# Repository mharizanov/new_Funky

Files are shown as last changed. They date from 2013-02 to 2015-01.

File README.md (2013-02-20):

Funky v2
=========

The Funky v2 is a miniature Arduino Leonardo clone with RFM12B module, intended for low power, battery operated remote node. Due to the miniature size, only few carefully selected pins are available as a side header, none the less that is more than sufficient to interface several sensors at a time.

Having gained experience with my Funky v1 project, I decided to create a new version. The project is a success, yet the areas I wanted to optimize are

The Attiny84 MCU that was used in the Funky v1 has limited RAM and sketch memory
The Attiny84 requires an ISP programmer for sketch uploading
The Attiny84 required a modified Arduino core
Many of the available Arduino libraries are not compatible with Attiny84
So the Funky v2 was created, see my posts here , here and here

Board size is mere 22×22.8mm (0.87″x0.89″) in size (same as Funky v1)
The MCU used in an Atmega32U4, the same MCU that Arduino Leonardo uses. This makes the Funky v2 a minuature Arduino Leonardo compatible board with RFM12b module
The Funky v2 has the Caterina bootloader, so programming is done with Arduino IDE via micro USB
Uses external 8Mhz crystal (can switch to internal RC clock in software as described here)
Operates on 3.3V

Read more http://harizanov.com/wiki/wiki-home/funky-sensor-v2/

Licensed under a Creative Commons Attribution-NonCommercial-ShareAlike 3.0 Unported License.

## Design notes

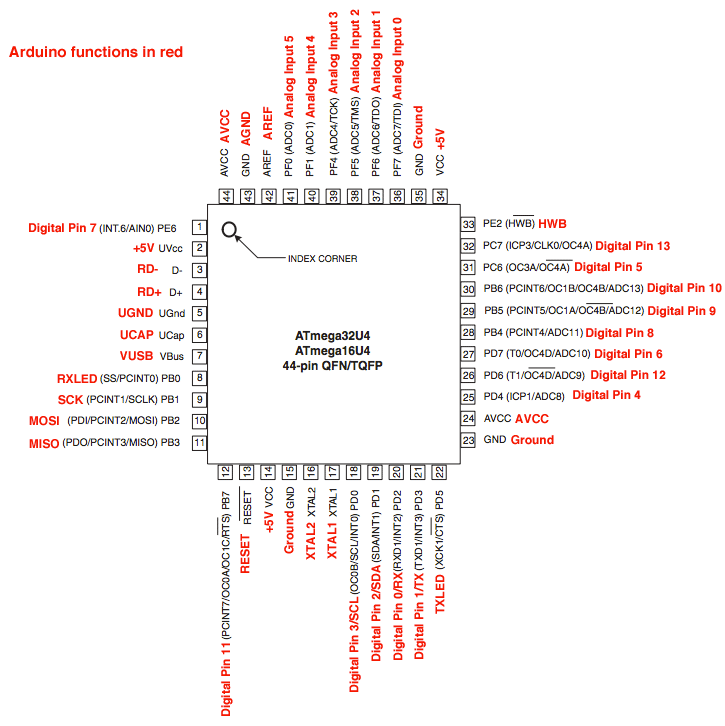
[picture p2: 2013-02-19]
32U4PinMapping.png

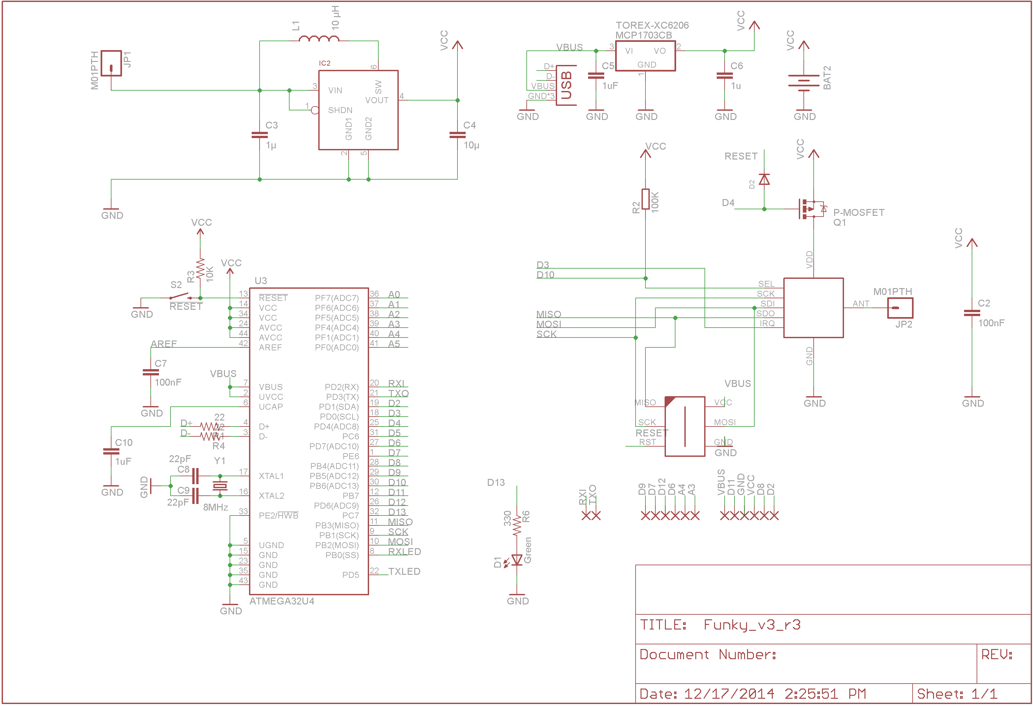
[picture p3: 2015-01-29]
board/v3/funky_v3_r3.sch.png

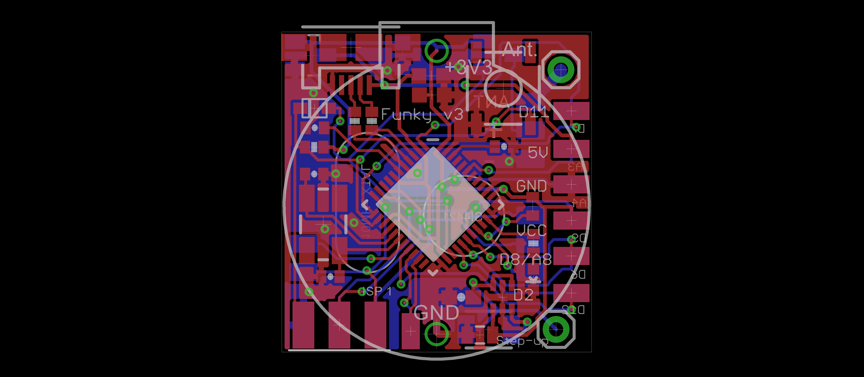
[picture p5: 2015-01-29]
board/v3/funky_v3_r3.brd.png

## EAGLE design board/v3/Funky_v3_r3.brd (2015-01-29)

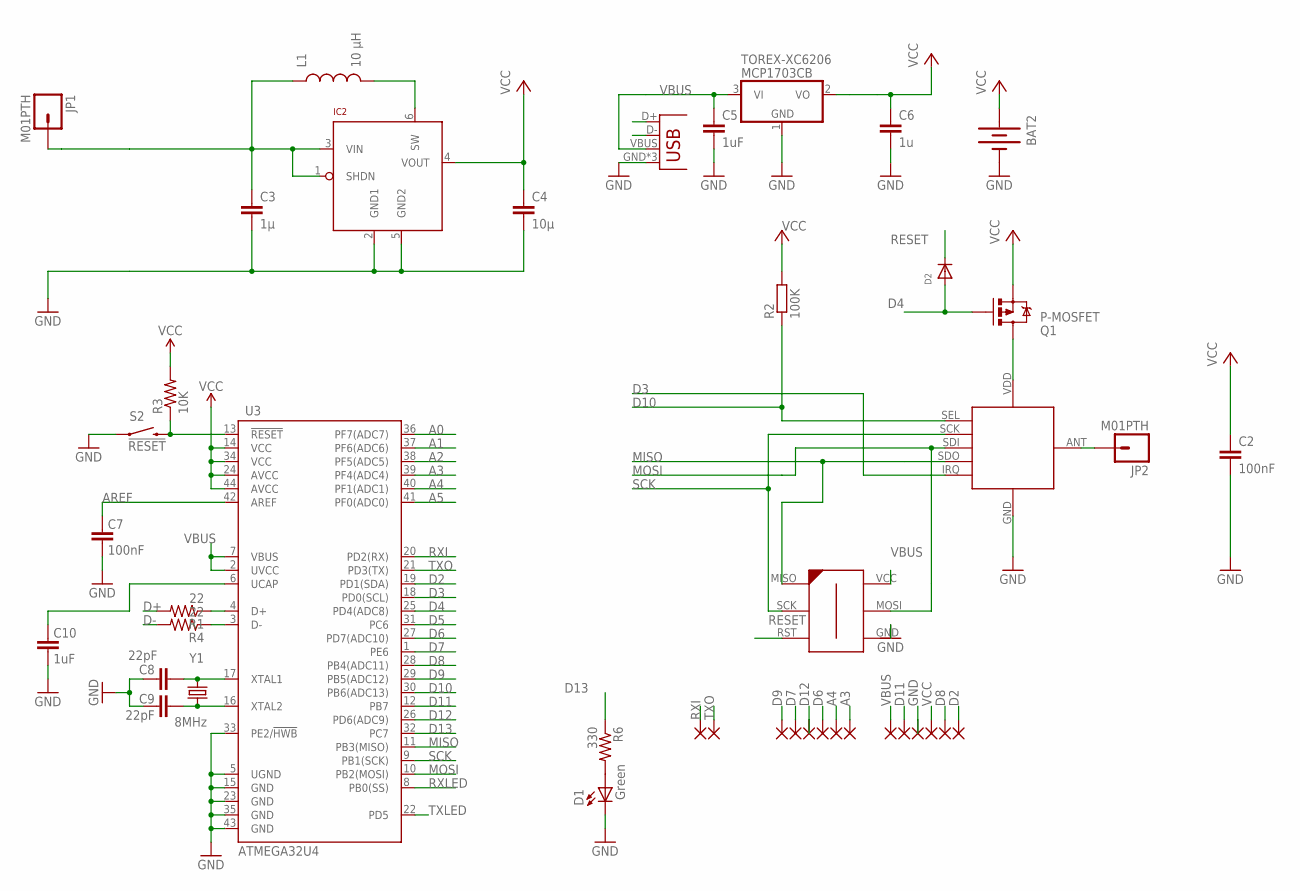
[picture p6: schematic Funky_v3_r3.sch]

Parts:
BAT2: BATTERY20PTH; BATTCOM_20MM_PTH
C2: 100nF; C0603K
C3: 1µ; 0603-CAP
C4: 10µ; 0805
C5: 1uF; C0603K
C6: 1u; C0603K
C7: 100nF; 0402-CAP
C8, C9: 22pF; 0402-CAP
C10: 1uF; 0402-CAP
D1: Green; LED-0603
D2: DIODESOD-323F; SOD-323F
IC2: LTC3525; SC70
JP1, JP2: M01PTH; 1X01
JP3: USB-MICROB
L1: 10 µH; 1210
PAD1, PAD2, PAD3, PAD4, PAD5, PAD6, PAD7, PAD8, PAD9, PAD10, PAD11, PAD12, PAD13, PAD14: SMD2; SMD1,27-2,54
Q1: P-MOSFET; SOT23
R1, R4: 22; 0402-RES
R2: 100K; R0402
R3: 10K; 0402-RES
R6: 330; 0402-RES
RFM12B1: RFM12B_MINPADS; RFM12B-MINPADS
S2: !RESET; TACTILE_SWITCH_SMD
TOREX-XC6206: MCP1703CB; SOT23
U3: ATMEGA32U4; QFN-44-NOPAD
U$2: AVR-ISP-6-EDGE; 6PAD_ISP
Y1: 8MHz; CRYSTAL-SMD-5X3

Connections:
A0: U3.36 (PF7(ADC7))
A1: U3.37 (PF6(ADC6))
A2: U3.38 (PF5(ADC5))
A3: PAD6.1, U3.39 (PF4(ADC4))
A4: PAD5.1, U3.40 (PF1(ADC1))
A5: U3.41 (PF0(ADC0))
AREF: C7.2, U3.42 (AREF)
D2: PAD12.1, U3.19 (PD1(SDA))
D3: RFM12B1.IRQ, U3.18 (PD0(SCL))
D4: D2.A, Q1.1 (G), U3.25 (PD4(ADC8))
D5: U3.31 (PC6)
D6: PAD4.1, U3.27 (PD7(ADC10))
D7: PAD2.1, U3.1 (PE6)
D8: PAD11.1, U3.28 (PB4(ADC11))
D9: PAD1.1, U3.29 (PB5(ADC12))
D10: R2.1, RFM12B1.SEL, U3.30 (PB6(ADC13))
D11: PAD7.1, U3.12 (PB7)
D12: PAD3.1, U3.26 (PD6(ADC9))
D13: R6.1, U3.32 (PC7)
D+: JP3.D+, R1.2
D-: JP3.D-, R4.2
GND: BAT2.2 (-), C2.2, C3.2, C4.2, C5.2, C6.2, C7.1, C8.2, C9.2, C10.1, D1.C, IC2.2 (GND1), IC2.5 (GND2), JP3.GND, JP3.MT1 (GND), JP3.MT2 (GND), PAD9.1, RFM12B1.GND, S2.1, TOREX-XC6206.1 (GND), U3.5 (UGND), U3.15 (GND), U3.23 (GND), U3.33 (PE2/!HWB), U3.35 (GND), U3.43 (GND), U$2.GND
MISO: RFM12B1.SDO (SDO/MISO), U3.11 (PB3(MISO)), U$2.MISO
MOSI: RFM12B1.SDI (SDI/MOSI), U3.10 (PB2(MOSI)), U$2.MOSI
unnamed: C9.1, U3.16 (XTAL2), Y1.1
unnamed: R1.1, U3.4 (D+)
unnamed: JP2.1, RFM12B1.ANT
unnamed: C8.1, U3.17 (XTAL1), Y1.3 (2)
unnamed: C10.2, U3.6 (UCAP)
unnamed: D1.A, R6.2
unnamed: R4.1, U3.3 (D-)
unnamed: Q1.3 (D), RFM12B1.VDD
unnamed: IC2.6 (SW), L1.2
RESET: D2.C, R3.1, S2.3 (2), U3.13 (!RESET), U$2.RST
RXI: PAD14.1, U3.20 (PD2(RX))
RXLED: U3.8 (PB0(SS))
SCK: RFM12B1.SCK, U3.9 (PB1(SCK)), U$2.SCK
TXLED: U3.22 (PD5)
TXO: PAD13.1, U3.21 (PD3(TX))
VBUS: C5.1, JP3.VBUS, PAD8.1, TOREX-XC6206.3 (VI), U3.2 (UVCC), U3.7 (VBUS), U$2.VCC
VCC: BAT2.1 (+), C2.1, C4.1, C6.1, IC2.4 (VOUT), PAD10.1, Q1.2 (S), R2.2, R3.2, TOREX-XC6206.2 (VO), U3.14 (VCC), U3.24 (AVCC), U3.34 (VCC), U3.44 (AVCC)
VIN: C3.1, IC2.1 (SHDN), IC2.3 (VIN), JP1.1, L1.1

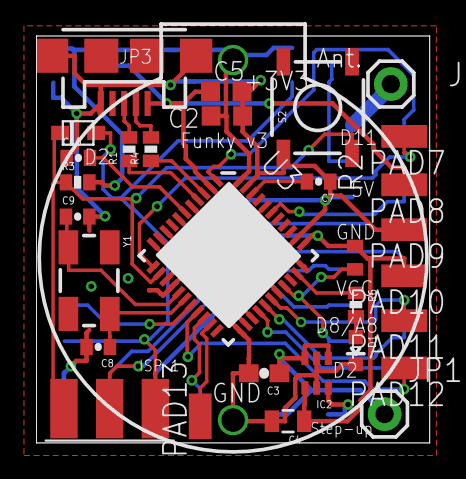
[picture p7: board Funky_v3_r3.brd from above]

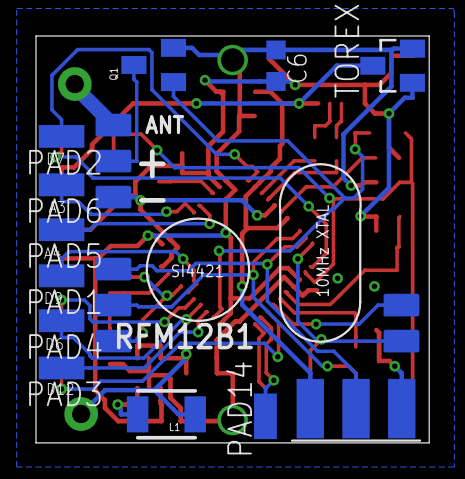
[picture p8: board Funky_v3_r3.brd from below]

Board: 2 copper layers, 21.8 x 22.6 mm, 43 parts (12 on the bottom side), 35 nets.

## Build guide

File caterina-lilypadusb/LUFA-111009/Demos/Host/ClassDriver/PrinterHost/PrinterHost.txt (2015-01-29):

/** \file
 *
 *  This file contains special DoxyGen information for the generation of the main page and other special
 *  documentation pages. It is not a project source file.
 */

/** \mainpage Printer Host Demo
 *
 *  \section Sec_Compat Demo Compatibility:
 *
 *  The following list indicates what microcontrollers are compatible with this demo.
 *
 *  - Series 7 USB AVRs (AT90USBxxx7)
 *
 *  \section Sec_Info USB Information:
 *
 *  The following table gives a rundown of the USB utilization of this demo.
 *
 *  <table>
 *   <tr>
 *    <td><b>USB Mode:</b></td>
 *    <td>Host</td>
 *   </tr>
 *   <tr>
 *    <td><b>USB Class:</b></td>
 *    <td>Printer Device</td>
 *   </tr>
 *   <tr>
 *    <td><b>USB Subclass:</b></td>
 *    <td>Bidirectional Protocol</td>
 *   </tr>
 *   <tr>
 *    <td><b>Relevant Standards:</b></td>
 *    <td>USBIF Printer Class Specification \n
 *        PCL Language Specification</td>
 *   </tr>
 *   <tr>
 *    <td><b>Usable Speeds:</b></td>
 *    <td>Low Speed Mode \n
 *        Full Speed Mode</td>
 *   </tr>
 *  </table>
 *
 *  \section Sec_Description Project Description:
 *
 *  Printer host demonstration application. This gives a simple reference
 *  application for implementing a USB Printer host, for USB printers using
 *  the bidirectional data encapsulation protocol and PCL language.
 *
 *  Upon connection of a compatible printer, the printer's device ID is sent
 *  to the AVR's serial port, and a simple test page is printed using the PCL
 *  printer language.
 *
 *  \section Sec_Options Project Options
 *
 *  The following defines can be found in this demo, which can control the demo behaviour when defined, or changed in value.
 *
 *  <table>
 *   <tr>
 *    <td>
 *     None
 *    </td>
 *   </tr>
 *  </table>
 */

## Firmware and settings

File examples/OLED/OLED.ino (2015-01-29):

/*
 
 http://harizanov.com/2013/06/miniature-oled-status-display-with-funky-v2/
 
 */
#include <SoftwareSerial.h>
SoftwareSerial mySerial(6, 8); // RX, TX, RX is set to some dummy pin

#include <JeeLib.h>

#include <RTClib.h>                 // Real time clock (RTC) - used for software RTC to reset kWh counters at midnight
#include <Wire.h>                   // Part of Arduino libraries - needed for RTClib
RTC_Millis RTC;

//--------------------------------------------------------------------------------------------
// RFM12B Settings
//--------------------------------------------------------------------------------------------
#define MYNODE 2             // Should be unique on network, node ID 30 reserved for base station
#define freq RF12_868MHZ     // frequency - match to same frequency as RFM12B module (change to 868Mhz or 915Mhz if appropriate)
#define group 210            // network group, must be same as emonTx and emonBase

#define ledpin 1

//---------------------------------------------------
// Data structures for transfering data between units
//---------------------------------------------------
typedef struct { int power1, power2, power3, Vrms, x1,x2,x3,x4,x5,x6;} PayloadTX;         // neat way of packaging data for RF comms
PayloadTX emontx;

typedef struct { int temperature; } PayloadGLCD;
PayloadGLCD emonglcd;

typedef struct { byte magic, hour, mins, sec; } PayloadBase;			// new payload def for time data reception
PayloadBase emonbase; 

typedef struct { int temperature, humidity,dummy; } PayloadFunky;
PayloadFunky emonfunky;

typedef struct { int temperature, batt, dummy; } PayloadSolar;
PayloadSolar emonsolar;

int hour = 0, minute = 0, second=0;
double usekwh = 0;
double otemp = 0, humi = 0, stemp=0;
double minotemp, maxotemp, minhumi, maxhumi, batt;
//double use_history[7];
//int cval_use;
//byte page = 1;


int tvx,tvy,tvradius,x2,y2,x3,y3;

//-------------------------------------------------------------------------------------------- 
// Flow control
//-------------------------------------------------------------------------------------------- 
unsigned long last_emontx;                   // Used to count time from last emontx update
unsigned long last_emonbase;                   // Used to count time from last emontx update
unsigned long fast_update;

//http://www.digole.com/images/file/Tech_Data/Digole_Serial_Display_Adapter-Manual.pdf
#define _Digole_Serial_UART_  //To tell compiler compile the special communication only, 
//other available is: _Digole_Serial_I2C_ and _Digole_Serial_SPI_
#include "DigoleSerial.h"
//--------UART setup, if you don't use UART, use // to comment following line
DigoleSerialDisp mydisp(&mySerial, 19200); //UART:Arduino UNO: Pin 1(TX)on arduino to RX on module
//--------I2C setup, if you don't use I2C, use // to comment following 2 lines
//#include <Wire.h>
//DigoleSerialDisp mydisp(&Wire,'\x27');  //I2C:Arduino UNO: SDA (data line) is on analog input pin 4, and SCL (clock line) is on analog input pin 5
//--------SPI setup, if you don't use SPI, use // to comment following line
//DigoleSerialDisp mydisp(8,9,10);  //SPI:Pin 8: data, 9:clock, 10: SS, you can assign 255 to SS, and hard ground SS pin on module
#define LCDCol 16
#define LCDRow 2
#define LCDW 127
#define LCDH 63

const unsigned char fonts[] = {6, 10, 18, 51, 120, 123};
const char *fontdir[] = {"0\xb0", "90\xb0", "180\xb0", "270\xb0"};

//icon converter http://www.digole.com/tools/PicturetoC_Hex_converter.php
prog_uchar tempimage[] PROGMEM = {
0x0f,0x0f
,0x1f,0x8f
,0x39,0xcf
,0x30,0xcf
,0x30,0xcf
,0x30,0xcf
,0x30,0xcf
,0x30,0xcf
,0x30,0xcf
,0x30,0xcf
,0x30,0xcf
,0x30,0xcf
,0x30,0xcf
,0x30,0xcf
,0x30,0xcf
,0x30,0xcf
,0x30,0xcf
,0x30,0xcf
,0x30,0xcf
,0x30,0xcf
,0x30,0xcf
,0x30,0xcf
,0x70,0xef
,0xe0,0x7f
,0xc0,0x3f
,0xc0,0x3f
,0xc0,0x3f
,0xc0,0x3f
,0xe0,0x7f
,0x70,0xef
,0x3f,0xcf
,0x1f,0x8f
};


void setup() {

    pinMode(ledpin,OUTPUT);
    digitalWrite(ledpin,HIGH);
    
    mydisp.begin();
        
    tvx=LCDW/2;
    tvy=LCDH/2;
    tvradius=LCDH/2 ;


    pinMode(A5,OUTPUT);
    digitalWrite(A5,LOW); //Start RFM12b
    
    delay(3000);
    
    /*----------for text LCD adapter and graphic LCD adapter ------------*/
    mydisp.clearScreen(); //CLear screen
    mydisp.disableCursor(); //disable cursor, enable cursore use: enableCursor();
    
    
    rf12_initialize(MYNODE, freq,group);
    digitalWrite(ledpin,LOW);
       
}

void loop() {

  if (rf12_recvDone())
  {
    if (rf12_crc == 0 && (rf12_hdr & RF12_HDR_CTL) == 0)  // and no rf errors
    {
      digitalWrite(ledpin,HIGH); //Blink LED to indicate packet received
      
      byte node_id = (rf12_hdr & 0x1F);
      if (node_id == 10) {emontx = *(PayloadTX*) rf12_data; last_emontx = millis();}
      if (node_id == 20) {
        emonfunky = *(PayloadFunky*) rf12_data; last_emontx = millis();
        otemp = (double)emonfunky.temperature / 100;
        humi = (double)emonfunky.humidity / 100;
      }
      
      if (node_id == 7) {emonsolar = *(PayloadSolar*) rf12_data; last_emontx = millis();     stemp = (double)emonsolar.temperature / 100; }

      
      if (node_id == 22)
      {
        
       emonbase = *(PayloadBase*) rf12_data;                           
       RTC.begin(DateTime(2013, 1, 1, emonbase.hour, emonbase.mins, emonbase.sec));
       last_emonbase = millis(); 
      
      } 
    }
    delay(10);  //Make LED blink more visible
    digitalWrite(ledpin,LOW);
  }


 
   
 //--------------------------------------------------------------------------------------------
  // Display update every 1000ms
  //--------------------------------------------------------------------------------------------
  if ((millis()-fast_update)>1000)
  {
    fast_update = millis();
    
    DateTime now = RTC.now();
    
    hour = now.hour();
    minute = now.minute();
    second = now.second();

    usekwh += (emontx.power1 * 1) / 3600000;
 
 
    draw1();  // Change to draw2 for analog clock
 
 
  }
}

void draw2()
{
  drawface();
  drawtime();
  drawtemp();

  mydisp.setFont(10);    
  resetpos(0);         

  if(hour<10){  // blank instead of leading digit
       mydisp.print(" ");
     }; 
   mydisp.print(hour);     
   mydisp.print(":");   

   if(minute<10) mydisp.print("0"); mydisp.print(minute); mydisp.print(" ");
     
}


void draw1(){
  
    mydisp.setFont(120);    
    resetpos(0);         
 //   mydisp.setTextPosAbs(0,31);
    if(hour<10){  // blank instead of leading digit
         mydisp.print(" ");
  //       mydisp.setTextPosAbs(30, 34);
     }; 
     mydisp.print(hour);     
     mydisp.print(":");   

//     mydisp.setTextPosAbs(64, 34); 
     if(minute<10) mydisp.print("0"); mydisp.print(minute); mydisp.print(" ");
 
   // The largest font only supports letters, no semicolumn, so we have to draw one
//    mydisp.drawCircle(60, 15, 2, 1);    
//    mydisp.drawCircle(60, 25, 2, 1);        
  
    mydisp.setFont(10);    
    resetpos(4);    
    mydisp.print("Power: ");     mydisp.print(emontx.power1);   mydisp.print("W ");   // mydisp.print((int)usekwh); mydisp.print("kWh) "); 
    resetpos(5);    
    mydisp.print("Solar: ");     mydisp.print(stemp);   mydisp.print("C ");    
    resetpos(6);    
    mydisp.print("Out: ");     mydisp.print(otemp);   mydisp.print("C Humi:"); mydisp.print((int)humi);   mydisp.print("% ");    

    drawtemp();        
//    mydisp.drawFrame(0, 0, 127, 64);
    
}

void resetpos(int pos) 
{
    mydisp.setPrintPos(0, pos, _TEXT_);

}


void drawtime()
{
 
mydisp.setColor(0);  
mydisp.drawCircle(tvx,tvy,tvradius-5,1);
mydisp.setColor(1);  

float angle = second*6 ;
angle=(angle/57.29577951) ; //Convert degrees to radians  
x3=(tvx+(sin(angle)*(tvradius-6)));
y3=(tvy-(cos(angle)*(tvradius-6)));
mydisp.drawLine(tvx,tvy,x3,y3);

angle = minute * 6 ;
angle=(angle/57.29577951) ; //Convert degrees to radians  
x3=(tvx+(sin(angle)*(tvradius-11)));
y3=(tvy-(cos(angle)*(tvradius-11)));
mydisp.drawLine(tvx,tvy,x3,y3);
angle = hour * 30 + int((minute / 12) * 6 )   ;
angle=(angle/57.29577951) ; //Convert degrees to radians  
x3=(tvx+(sin(angle)*(tvradius-15)));
y3=(tvy-(cos(angle)*(tvradius-15)));
mydisp.drawLine(tvx,tvy,x3,y3);

}


void drawface() 
{
  
//clock face  
 mydisp.drawCircle(tvx,tvy,tvradius,0);
//hour ticks
for( int z=0; z < 360;z= z + 30 ){
  //Begin at 0° and stop at 360°
  float angle = z ;
  angle=(angle/57.29577951) ; //Convert degrees to radians
  x2=(tvx+(sin(angle)*tvradius));
  y2=(tvy-(cos(angle)*tvradius));
  x3=(tvx+(sin(angle)*(tvradius-4)));
  y3=(tvy-(cos(angle)*(tvradius-4)));

  mydisp.drawLine(x2,y2,x3,y3);
  
}
}

void drawtemp()
{
    mydisp.drawBitmap(115, 0, 12, 32, tempimage);
    
    if(stemp>30) { //if solat remperature is greater than 30

    // fill in the thermometer base      
    mydisp.drawCircle(120, 26, 2, 1);    
    mydisp.drawCircle(121, 26, 2, 1);        
    
    //calculate the lenght of the mercury bar, solar should range from 30 to 95 degrees, we scale that to 0-20 pixels bar
    int barlen=map(stemp,30,95,0,20);
    mydisp.drawBox(120,23-barlen,1,barlen);
    }  
}

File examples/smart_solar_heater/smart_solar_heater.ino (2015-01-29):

// Maetin's smart hot water tank controler project, check it out here http://harizanov.com/2013/09/smart-iot-solar-hot-water-tank-controller/
#include <OneWire.h>   // http://www.pjrc.com/teensy/arduino_libraries/OneWire.zip
#include <DallasTemperature.h>  // http://download.milesburton.com/Arduino/MaximTemperature/DallasTemperature_371Beta.zip
#define TEMPERATURE_PRECISION 9
 
#define ONE_WIRE_BUS 13

#include <avr/wdt.h>


// Setup a oneWire instance to communicate with any OneWire devices 
// (not just Maxim/Dallas temperature ICs)
OneWire oneWire(ONE_WIRE_BUS);
 
// Pass our oneWire reference to Dallas Temperature.
DallasTemperature sensors(&oneWire);

// Connect D8 to SET, D2 to RESET

#define LED 1
#define SET 2
#define RESET 8
#define rsdelay 50
#define QUERY_INTERVAL 30000
#define SEND_INTERVAL 50000
#define TZOFFSET 0

#include <avr/power.h>


#include <JeeLib.h>
//--------------------------------------------------------------------------------------------
// RFM12B Settings
//--------------------------------------------------------------------------------------------
#define MYNODE 7             // Should be unique on network, node ID 30 reserved for base station
#define freq RF12_868MHZ     // frequency - match to same frequency as RFM12B module (change to 868Mhz or 915Mhz if appropriate)
#define group 210            // network group, must be same as emonTx and emonBase


#define ACK  0            // Require ACK?
#define RETRY_PERIOD 1    // How soon to retry (in seconds) if ACK didn't come in
#define RETRY_LIMIT 5     // Maximum number of times to retry
#define ACK_TIME 15       // Number of milliseconds to wait for an ack

#define GATEWAYID 16  
#define EMONCMS_CONTROL_FEEDID (int)93; 

#include <RTClib.h>                 // Real time clock (RTC) - used for software RTC to reset kWh counters at midnight
#include <Wire.h>                   // Part of Arduino libraries - needed for RTClib
RTC_Millis RTC;


static byte numSensors;
static byte timeset=0;
static byte relaystatus=0;

void setrelay() {
  
  digitalWrite(SET,HIGH);
  digitalWrite(LED,HIGH);
  delay(rsdelay);
  digitalWrite(SET,LOW);
  digitalWrite(LED,LOW);
  delay(500);
} 


void resetrelay() {  
  
  digitalWrite(RESET,HIGH);
  digitalWrite(LED,HIGH);
  delay(rsdelay);
  digitalWrite(RESET,LOW);
  digitalWrite(LED,LOW);
  delay(500);  
}

typedef struct { int temperature, batt, dummy; } PayloadSolar;
PayloadSolar emonsolar;

typedef struct { byte magic, hour, mins, sec; } PayloadBase;			// new payload def for time data reception
PayloadBase emonbase; 

int hour = 0, minute = 0, second=0;
unsigned long last_emonbase, last_sent, last_gatequery, feed_update;

typedef struct { byte node_id; unsigned int feed_id; float feed_val;} askStruct;			// new payload def for time data reception
askStruct askpayload; 

static int feed_val;


void setup(){
 // clock_prescale_set(clock_div_1);   //Make sure we run @ 8Mhz; not running on battery so go full speed

  wdt_disable();
  //Relay driving pins
  pinMode(SET,OUTPUT);
  pinMode(RESET,OUTPUT);
  resetrelay();

  Serial.begin(9600);

  for (byte i=0;i<10;i++,delay(1000),Serial.print('.'));
  
  //On board LED
  pinMode(LED,OUTPUT);
  digitalWrite(LED,HIGH);
  
  pinMode(A5,OUTPUT);
  digitalWrite(A5,LOW); //Start RFM12b
  delay(500);
  rf12_initialize(MYNODE, freq,group);
  
    // Start up the library
  sensors.begin(); 
  numSensors=sensors.getDeviceCount(); 

  digitalWrite(LED,LOW);
  
  wdt_enable(WDTO_8S); 
  
}
void loop() {
   
  wdt_reset();
     
   if (rf12_recvDone())
  {
    if (rf12_crc == 0 && (rf12_hdr & RF12_HDR_CTL) == 0)  // and no rf errors
    {
      digitalWrite(LED,HIGH); //Blink LED to indicate packet received
      
      byte node_id = (rf12_hdr & 0x1F);
      
      if (node_id == GATEWAYID)
      {        
       emonbase = *(PayloadBase*) rf12_data;                           
       
       if(emonbase.magic=='t') { //Valid emonbase time packet?
         RTC.begin(DateTime(2013, 1, 1, emonbase.hour, emonbase.mins, emonbase.sec));
         last_emonbase = millis(); 
         timeset=1;
         Serial.print(F("Time is:"));Serial.print(emonbase.hour);Serial.print(":");Serial.println(emonbase.mins);
       }
       
      }
      
      if (node_id == GATEWAYID)  // Gateway's response to query for emoncms feed value
        {        
         askpayload = *(askStruct*) rf12_data;                                  
           
         if((askpayload.node_id & 0x1F )== GATEWAYID) {
           Serial.print(F("Node id:"));Serial.println(askpayload.node_id);         
           Serial.print(F("Feed id:"));Serial.println(askpayload.feed_id);
           Serial.print(F("Feed val:"));Serial.println(askpayload.feed_val);
           feed_val=(int)askpayload.feed_val;
           feed_update=millis();
         }
         
        } 
      
    delay(10);  //Make LED blink more visible
    digitalWrite(LED,LOW);
  }
  }

  if(millis()-last_sent>SEND_INTERVAL) {

    digitalWrite(LED,HIGH); //Blink LED to indicate packet received 
    sensors.requestTemperatures(); // Send the command to get temperatures    
    emonsolar.temperature=sensors.getTempCByIndex(0)*100;
    emonsolar.batt=readVcc();
    rfwrite();      
    last_sent=millis();
    delay(10);  //Make LED blink more visible
    digitalWrite(LED,LOW);
    Serial.print(F("Temperature is:"));Serial.println(emonsolar.temperature);
  }
 

  if(millis()-last_gatequery>QUERY_INTERVAL) {

    digitalWrite(LED,HIGH); //Blink LED to indicate packet received 

    askpayload.node_id=MYNODE;
    askpayload.feed_id=EMONCMS_CONTROL_FEEDID;
    askpayload.feed_val=0;
    
    byte i = 0; while (!rf12_canSend() && i<10) {rf12_recvDone(); i++;}
    rf12_sendStart(RF12_HDR_DST | GATEWAYID, &askpayload, sizeof askpayload);
    rf12_sendWait(0);
    
    Serial.println(F("Sent feed query request"));
    
    last_gatequery=millis();
    delay(10);  //Make LED blink more visible
    digitalWrite(LED,LOW);
       
  }
  
  if(millis()%5000 ==0) controlrelay();
}
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

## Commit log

2013-01-05 some clearance fix
    [New.brd]
2013-02-19 PCB revision after the MISO/MOSI pins were messed up
    [New.brd, New.sch]
2013-02-25 Bash script to run on Raspberry Pi
2013-03-17 Revert "example"
    This reverts commit 1f9ad8d22b45befcb35b8a9bb4ed2c9c1b9cff3c.
    [New.GBL, New.GBO, New.GBP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]
2013-03-26 Rev 1.1 of the board
    added MOSFET to control RFM12B's power state
    [New_rev1.brd, New_rev1.sch]
2013-03-28 ATmega32U4 Timer 4 experiments
2013-03-29 Fix for Funky v2
    [RFM12_to_Pi.ino]
2013-04-04 I2C example
2013-06-12 reduce BOD to 2.2V
2013-06-18 Fixed pin number for latest PCB layout
    [Funky_DS18B20_to_Serial.ino]
2013-06-18 pin fix
2013-06-18 updated for the latest pcb revision with mosfet
2013-06-22 Fixed Timer 0 disable
    [Funky_DS18B20_plus_powersave.ino]
2013-06-22 optimization for a shorted led blink to save power
    [Funky_DS18B20_plus_powersave.ino]
2013-07-01 rev 2 pcb files
    [New_rev2.brd, New_rev2.sch]
2013-07-06 updated code for better power efficiency
2013-07-14 temperature to RGB example
2013-07-19 Fixed LED pin number (used workerB's)
    [Funky_DS18B20_plus_powersave.ino]
2013-07-19 messed up code with workerB pins :( now fixed
    [Funky_DS18B20_plus_powersave.ino]
2013-07-20 read vcc twice fix
    [Funky_DS18B20_plus_powersave.ino]
2013-07-29 flood sensor example
2013-08-04 battery level measurement fix
    [Funky_DS18B20_plus_powersave.ino, RFM12B_test.ino]
2013-08-24 door sensor example
2014-01-15 Funky v3 revision 3
    [Funky_v3_r3.brd, Funky_v3_r3.sch]
2015-01-29 Update the project folder to latet
    [ConfiguringApps.txt, Funky_v3_r3.brd, Funky_v3_r3.sch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]
2015-01-29 Adding .PNGs of board and schematic
2015-02-17 Correcting a missed LED_PIN define
    Correcting a missed LED_PIN define
    [RF12demo_funkyv3.ino]
2015-02-18 Fixed RFM12B_test to work for v3
    [RF12demo_funkyv3.ino, RFM12B_test.ino]
2015-02-22 DHT22 example fix for Funky v3
    [Funky_DHT22_plus_powersave.ino]
2015-03-31 Jeelib is now fixed, so removing this comment
    [RF12demo_funkyv3.ino]

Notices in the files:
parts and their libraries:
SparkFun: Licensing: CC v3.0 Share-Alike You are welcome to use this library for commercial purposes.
